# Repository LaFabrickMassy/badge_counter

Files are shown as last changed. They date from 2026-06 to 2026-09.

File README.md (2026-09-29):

# Compteur de fréquentation

## Objectif

Ce projet décrit un appareil qui permet de mesurer la fréquentation d'un lieu.  
Il a pour prérequis que tous les visiteurs disposeraient d'un badge à technologie NFC (typiquement salariés d'une entreprise), et badgent volontairement (présence nécessaire d'un panneau d'invitation au badgeage).

## Principe
Les badgeages sont enregistrés, et les statistiques sont accessible sur un serveur web local (hotspot) sous forme de statistiques par période de temps (nombre de visites mensuelles, nombre de visiteurs uniques mensuels).  
L'appareil est complètement autonome et n'est relié a rien si ce n'est son alimentation électrique.  
L'appareil n'enregistre que des identifiants de badge (nécessaire pour déterminer les visiteurs uniques), et n'a pas accès aux données personnelles (nom du porteur du badge par exemple).  

## Fonctionnement 
Au badgeage, un musique aléatoire (parmi 4 pour l’instant) est jouée.  
Il y a un « anti-passback », qui inhibe le badgeage pendant 1h pour chaque badge.  
Discriminant de badge : identifiant à n chiffres sur un bloc de m octets (cas des badges des salariés du site du FabLab).  

## Restitution des données

Un hotspot wifi et un serveur web sont démarrés lorsqu’on appuie sur le bouton de coté (et s’arrêtent au bout de 10 minutes). Les credentials (SSID, pwd, ip) sont affichés sur l’écran lorsque le serveur est actif.
Le serveur web donne accès aux données de fréquentation mensuelles sous forme tabulaire et graphique.
Il y a une page d’administration qui permet de  
- regler l’heure et de
- télécharger un fichier de synthèse des statistiques,
- téléchargerle fichier de log (timestamp, id badge)
- mais aussi d’écraser le fichier de log (attention, remise à zero des stats). Par sécurité, un backup est fait sur la carte, accessible uniquement physiquement (par lecture de la carte sd sur un pc).

# Ajout d'une nouvelle musique
1. décrire la partition sous forme d'une succession de notes. Chaque note est un couple (hauteur, durée). La hauteur de la note s'écrit suivant la notation anglo-saxone (voir documentation dans le fichier `songs.py` )
2. Rajouter cette liste de couples sous forme d'une variable liste python dans le fichier `songs.py` (voir exemples existants)
3. Rajouter cette variable à la liste des musiques `songs`, en précisant un tempo
4. En utilisant vscode, uploader le fichier songs.py sur le pico, à l'aide d'un cordon USB-microUSB

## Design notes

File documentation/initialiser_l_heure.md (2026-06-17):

# Initialiser l'heure du compteur de badge

Le compteur de badge dispose d'une horloge sauvegardée par pile. Il n'est donc pas nécessaire de réinitaliser l'heure à chaque fois qu'on le branche.  
Toutefois lorsque l'on doit changer la pile, l'heure n'est pas maintenue et il faut la réinitialiser à l'heure courante.  
L'appareil n'étant pas branché à internet, il ne peut pas déteminer l'heure sur le réseau. Une procédure manuelle est nécessaire.  

Cette procédure implique de modifier un script python pour saisir l'heure à laquelle on veut initialiser l'appareil, puis d'executer ce script.

## Procédure vscode

1. Condition initiale : l'outil VSCode est installé sur un ordinateur, ainsi que le plugin Micropico
2. Branchez le lecteur de badge en USB
3. Ouvrir VSCode
4. Créer ou ouvrir un répertoire micropico: ceci est nécessaire pour avoir accès au filesystème du Pico
    1. Dans vscode menu File / Open folder...
    2. Creez un nouveau répertoire quelconque et sélectionnez le pour ouverture
    3. Initialisez le en tant que répertoire micopico : 
        1. Ouvrez la palette des commandes (Ctrl + shift + p)
        2. Micropico: initialize micropico project
5. Accédez au file systeme du pico : dans la barre d'état en bas de vscode, cliquez sur "Toggle Mpy FS"
6. Un répertoire supplémentaire apparait dans le workspace : Mpy Remote Workspace
7. Cliquez sur le fichier "initialize_time.py" pour l'ouvrir
8. Modifiez la variable `initial_time_tuple` pour mettre l'heure cible
9. Enregistrez le fichier
10. Executez-le : le fichier sélectionné, cliquez sur "Run" dans la barre d'état
11. Le pico est maintenant à l'heure de la variable. Si la pile est chargé, cette heure est maintenue à jour avec le temps qui passe, sinon ce sera l'heure utilisée à chaque redémarrage.

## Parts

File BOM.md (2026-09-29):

# Bill Of Materials

## Composants

| Intitulé | Modèle | Prix indicatif |Lien |
| - | - | - |- |
| Microcontroleur | Rpi Pi Pico 2 W | 7,80 € | https://www.kubii.com/fr/cartes-micro-controleurs/4377-2357-raspberry-pi-pico-2-3272496319394.html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 |
| Carte de prototypage à souder | Upesy Medium | 2 € (x2) | https://www.upesy.fr/products/upesy-protoboard-breadboard-medium |
| Module NFC |  NFC RFID V3 PN532 | 4 €  | AliExpress |
| Module Real Time clock |  DS3231 AT24C32 IIC | 3,50 €  | AliExpress |
| Module SD Card |  SD CARD module | 1 €  | AliExpress |
| Ecran OLED |SSD1306 | 2 € | AliExpress |
| Buzzer Passif | Passive buzzer | 1,50 € | AliExpress |
| Bouton poussoir SPST | Bouton poussoir SPST (single pole, single throw)| Broutilles | AliExpress |
| Convertisseur DC / DC| LM2596 SMD | 1,10 € | AliExpress |
| Adaptateur secteur | Adaptateur secteur universel | 10,90 € | https://www.gotronic.fr/art-adaptateur-pce600.htm|
| Embase alimentation | Embase 5.5 x 2.1 | 0,40 € | https://www.gotronic.fr/art-embase-alim-sa215-14966.htm |
| Connecteurs JST-XH | Kit de connecteurs JST-XH (pas de 2.54mm) 2, 3, 4, 6 et 8 pins | 5 € |  AliExpress |
| Cables présertis JST XH | jst cables 10 cm | | AliExpress | 
| Connecteur Dupond | 2, 3, 4, 6 et 8 pins | Clopinettes | AliExpress |

## Consommables
- Fil d'étain à souder sans plomb
- Fil électrique 0,14mm²
- filament PLA pour imprimante 3D (~100g)
- chute de plexiglas 2,5mm
- quincaillerie :
  - vis M2.5 x 12
  - vis M2.5 x 40
  - vis M2 x 12
  - inserts laiton pour PLA M2.5
  - inserts laiton pour PLA M2

## Outils
- Fer à souder
- Pince coupante
- Pince à sertir
- tournevis multi tool
- scie (pour le plexiglas)
- perceuse (pour le plexiglas)
- PC (dev Python, modelisation du boitier)
- Cable USB-B - micro-USB
- Plaque d'essais sans soudure + fils de connexion

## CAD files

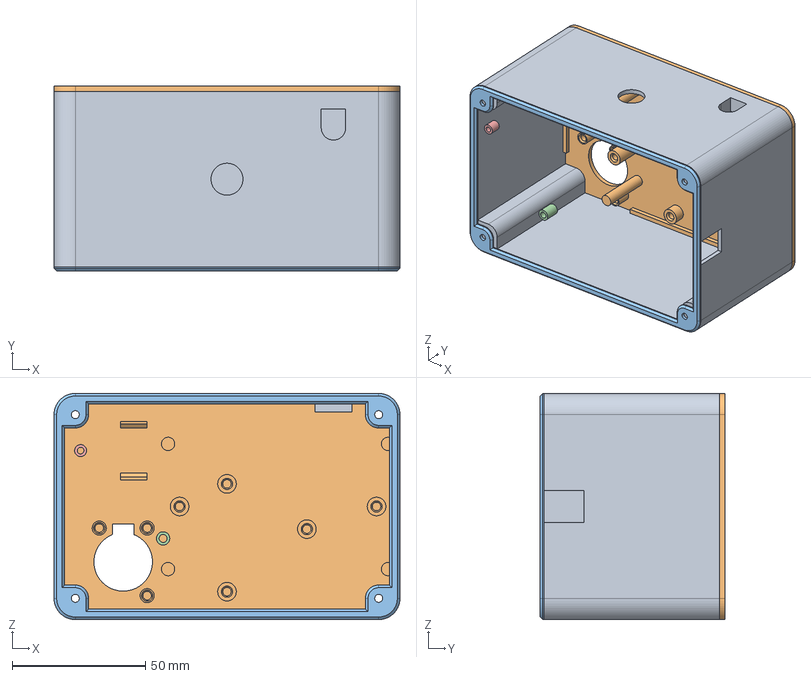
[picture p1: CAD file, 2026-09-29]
casing/casing_lecteur_badge.FCStd
130.0 x 69.5 x 85.0 mm
Walls
Back
Couvercle
EntretoiseM2.5
EntretroisM2

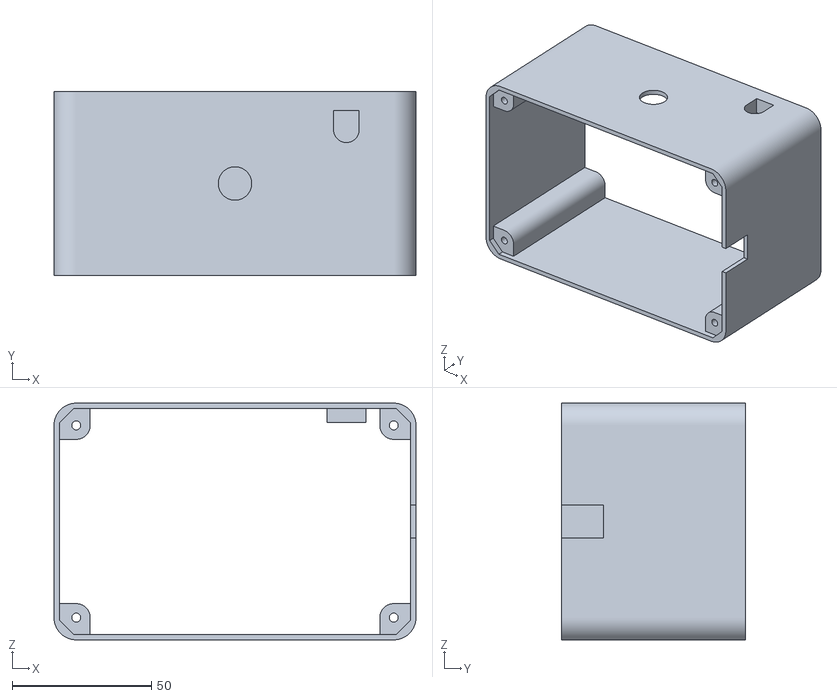
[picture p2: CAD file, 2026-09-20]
casing/stl/casing_lecteur_badge-Walls.stl
130.0 x 66.0 x 85.0

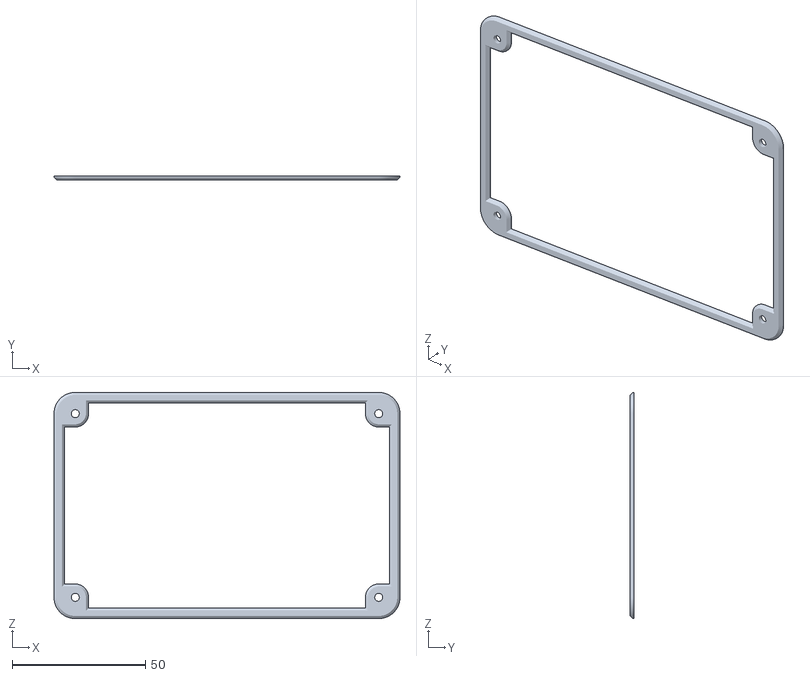
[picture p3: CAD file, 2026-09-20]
casing/stl/casing_lecteur_badge-Couvercle.stl
130.0 x 1.50 x 85.0

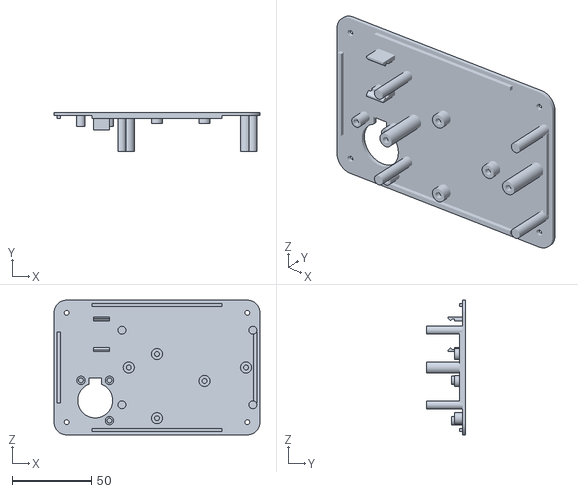
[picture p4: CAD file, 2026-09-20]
casing/stl/casing_lecteur_badge-Back.stl
130.0 x 24.8 x 85.0

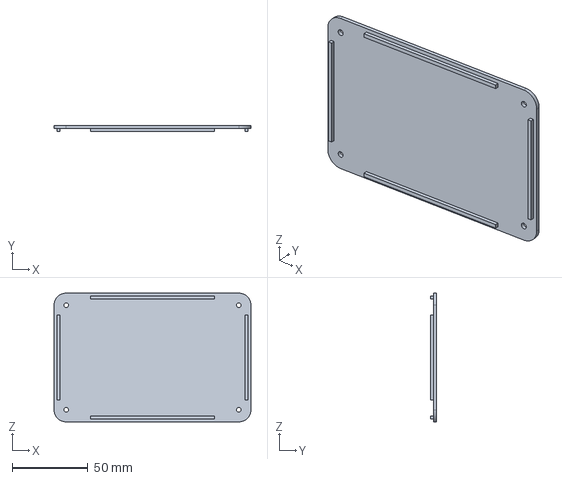
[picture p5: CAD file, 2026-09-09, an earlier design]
casing/casing_lecteur_badge_old.FCStd
130.0 x 4.00 x 85.0 mm

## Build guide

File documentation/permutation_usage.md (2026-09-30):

# Permutation de l'usage du lecteur de badge

Bien que le lecteur de badge ait été conçu pour mesurer la fréquentation d'un lieu unique, il est possible de permuter ponctuellement son utilisation pour des evenements spécifiques.

## Principe de fonctionnement

Le lecteur de badge met à jour à chaque évènement les informations de fréquentation dans deux fichiers internes :
- Fichier `data.txt` : Le lecteur de badge enregistre dans un fichier, à chaque badgeage, le numéro de badge et la date/heure de l'évènement.
- Fichier `stats.csv` : les données d'évènement sont exploitées pour en déduire le nombre de visites et de visiteurs uniques par période mensuelle

Il est possible de télécharger ces deux fichiers depuis l'interface web de l'appareil.  
L'interface web permet également d'uploader un fichier `data.txt` sur l'appareil, et d'écraser le fichier interne existant.

## Accès à l'interface web

1. Appuyer sur le bouton situé sur le coté de l'appareil.
2. Cela active un "hotspot" wifi ainsi qu'un serveur web.
3. Pour y accéder : 
    - noter les informations (nom du réseau wifi, password, adresse ip du serveur) qui s'affichent sur l'écran du lecteur de badge
    - sur un téléphone, ou un PC sans VPN tel que ceux du fablab, connectez-vous au réseau wifi du lecteur
    - ouvrez un navigateur web et saisissez l'adresse ip précisée en tant qu'adresse web (par exemple `192.168.4.1`)
    - le navigateur affiche les statistiques de fréquentation 
    - un lien vous permet d'accéder aux fonctions d'administration, y compris les fonctions de download et d'upload
4. Le service web se désactive après un nouvel appui sur le bouton, ou au bout de 10 minutes

## Procédure de permutation

1. Sauvergarde des données du Fablab : télécharger le fichier `data.txt` et le sauvegarder dans un répertoire dédié au Fablab
2. Mise à zéro des statistiques : créer un fichier `data.txt` vide et l'uploader sur le serveur web
3. Exploitation du lecteur pour le nouvel usage...
4. Exploitation des données : depuis le serveur web, downloader les fichiers `data.txt` et `stats.csv` dans un répertoire dédié à l'évenement
5. Restauration des données Fablab : sur le serveur web, uploader le fichier `data.txt` sauvergardé depuis l'étape 1.

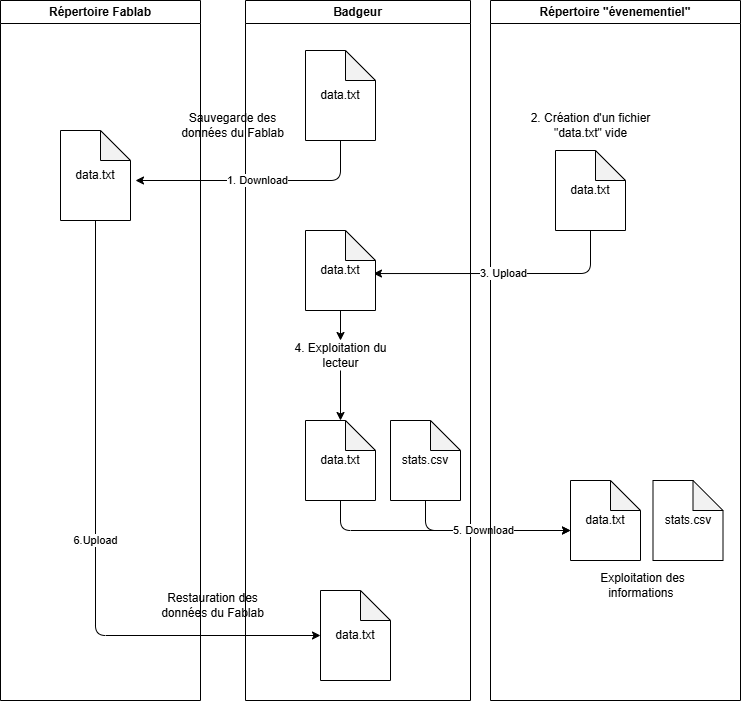
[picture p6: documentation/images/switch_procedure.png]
figure permutation


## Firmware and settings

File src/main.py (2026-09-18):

from machine import Pin, I2C, SPI
import machine
import network
import socket
import SSD1306
import urtc
import time
import sdcard
import uos
import NFC_PN532 as nfc
from buzzer import Buzzer, hello_world, game_over, bipbip
from attendancemodel import AttendanceModel, BadgingStatus
from webserver import WebService

class DisplayState:
    Counts = 0
    Params = 1

class BadgeCounter:
    
    def __init__(self, 
                 display_i2c=0, display_sda=20, display_scl=21,
                 rtc_i2c=1, rtc_sda=6, rtc_scl=7,
                 sd_spi=0, sd_mosi=3, sd_miso=4, sd_sck=2, sd_cs=1,
                 nfc_spi=1, nfc_mosi=11, nfc_miso=12, nfc_sck=10, nfc_rst=16, nfc_cs=13, nfc_irq=17,
                 buzzer_pin=15, button_pin=14, wifi_ssid="BadgeCounter", wifi_password="fablab2026"):
        
        # display communication
        self.display_i2c = I2C(id=display_i2c, sda=Pin(display_sda), scl=Pin(display_scl), freq=400000)
        
        # rtc communication
        self.rtc_i2c = I2C(id=rtc_i2c, scl=Pin(rtc_scl), sda=Pin(rtc_sda))
        
        # sd card communication
        self.sd_spi = machine.SPI(sd_spi,
                  baudrate=1000000,
                  polarity=0,
                  phase=0,
                  bits=8,
                  firstbit=machine.SPI.MSB,
                  sck=machine.Pin(sd_sck),
                  mosi=machine.Pin(sd_mosi),
                  miso=machine.Pin(sd_miso))
        self.sd_cs = sd_cs
        
        # nfc communication
        self.nfc_rst = nfc_rst
        self.nfc_cs = nfc_cs
        self.nfc_irq = nfc_irq
        self.nfc_spi = SPI(nfc_spi, baudrate=400000, sck=Pin(nfc_sck), mosi=Pin(nfc_mosi), miso=Pin(nfc_miso))
        
        # buzzer
        self.buzzer = Buzzer(buzzer_pin)
        self.button = Pin(button_pin, Pin.IN, Pin.PULL_UP)
        self.button_value = self.button.value()
        self.display_state = DisplayState.Counts
        self.webservice = None
        self.socket_server = None
        self.params_mode_started_at = None

        self.wifi_ssid = wifi_ssid
        self.wifi_password = wifi_password

        
    def init_display(self):
        self.display = SSD1306.SSD1306_I2C(128, 64, self.display_i2c)
        
    def init_rtc(self):
        self.rtc = urtc.DS3231(self.rtc_i2c)
        
    def init_sd(self):
        # Configure the Chip Select pin
        CS_SD = machine.Pin(self.sd_cs, machine.Pin.OUT)

        # Initialize the SD card object
        sd = sdcard.SDCard(self.sd_spi, CS_SD)

        # Mount the FAT filesystem
        vfs = uos.VfsFat(sd)
        uos.mount(vfs, "/sd")
        
    def init_nfc(self):
        rst = Pin(self.nfc_rst, Pin.OUT)
        rst.value(0)
        cs = Pin(self.nfc_cs, Pin.OUT)
        cs.on()
        ir = Pin(self.nfc_irq, Pin.IN)

        time.sleep(0.1)
        rst.value(1)
        time.sleep(0.5)  # Wait for PN532 to boot into SPI mode

        # SENSOR INIT
        self.pn532 = nfc.PN532(self.nfc_spi, cs, irq=ir, debug=False)
        ic, ver, rev, support = self.pn532.get_firmware_version()
        print('Found PN532 with firmware version: {0}.{1}'.format(ver, rev))

        # Configure PN532 to communicate with MiFare cards
        self.pn532.SAM_configuration()
        
    def init_buzzer(self):
        # there is nothing to init, just play song
        self.buzzer.play(hello_world)
        
    def init_data(self):
        # initialiser les données
        # le modele doit etre initialisé après rtc
        self.model = AttendanceModel(rtc=self.rtc, datafilename='/sd/data.txt')
        self.model.read_data()
        self.model.export_stats_to_csv()
        try:
            filesystem_stats = uos.statvfs('/sd')
            free_space = filesystem_stats[0] * filesystem_stats[4]
            free_space_percent = (filesystem_stats[4] * 100) / filesystem_stats[2]
            data_size = uos.stat(self.model.datafilename)[6]
            print("\nSD card free space: {} Mbytes ({:.2f}%)".format(
                free_space / (1024 * 1024), free_space_percent))
            print("data.txt size: {} bytes\n".format(data_size))
        except OSError as error:
            print("Unable to read SD card usage: {}".format(error))
        return

    def init_wifi_ap(self):
        self.wlan = network.WLAN(network.AP_IF)
        self.wlan.active(True)
        self.wlan.config(
            essid=self.wifi_ssid,
            password=self.wifi_password,
        )

        while not self.wlan.active():
            time.sleep_ms(100)

        print("Wi-Fi access point started")
        print("SSID:", self.wifi_ssid)
        print("Address: http://{}/".format(self.wlan.ifconfig()[0]))
    
    def init_webservice(self):
        self.socket_server = socket.socket()
        self.socket_server.setsockopt(socket.SOL_SOCKET, socket.SO_REUSEADDR, 1)
        self.socket_server.bind(("0.0.0.0", 80))
        self.socket_server.listen(1)
        self.socket_server.setblocking(False)
        
        self.webservice = WebService(self.model, self.socket_server)

    def start_params_mode(self):
        self.init_wifi_ap()
        self.init_webservice()
        self.params_mode_started_at = time.ticks_ms()

    def stop_params_mode(self):
        if self.socket_server is not None:
            self.socket_server.close()
            self.socket_server = None
        self.webservice = None
        self.params_mode_started_at = None
        self.wlan.active(False)

    def check_params_timeout(self):
        if (self.display_state == DisplayState.Params and
                self.params_mode_started_at is not None and
                time.ticks_diff(time.ticks_ms(), self.params_mode_started_at) >= 10 * 60 * 1000):
            self.display_state = DisplayState.Counts
            self.stop_params_mode()
        
    def refresh_display(self):

        if self.display_state == DisplayState.Counts :   
            current_datetime = self.rtc.datetime()
            sdate = f"{current_datetime.year:04d}-{current_datetime.month:02d}-{current_datetime.day:02d}"
            stime = f"{current_datetime.hour:02d}:{current_datetime.minute:02d}:{current_datetime.second:02d}"
            nvisits = f"Visites: {self.model.visits()}"

            self.display.fill(0) 
            self.display.text(sdate, 0,0, 1)
            self.display.text(stime, 0,10, 1)
            self.display.text(nvisits, 0, 24, 1)
            self.display.show()  
        else :
            self.display.fill(0) 
            self.display.text("SSID :", 0,0, 1)
            self.display.text(f"{self.wifi_ssid}", 0, 10, 1)
            self.display.text("Pwd :", 0, 22, 1)
            self.display.text(f"{self.wifi_password}", 0, 32, 1)
            self.display.text("ip :", 0, 44, 1)
            self.display.text(f"{self.wlan.ifconfig()[0]}", 0, 54, 1)
            self.display.show()  


        
    def read_badge(self):
        uid, length = self.pn532.read_passive_target_fablab(timeout=1000) 
        if uid is not None:
            numbers = [i for i in uid]
            print(f"UID: {numbers}, frame_length: {length}")
            # play(imperial_march)
            result = self.model.handle_event(uid, length)
            print(f"Result : {result}")
            if result == BadgingStatus.PASSBACK:
                self.buzzer.play(game_over)
                self.refresh_display()
            elif result == BadgingStatus.NOT_THALES:
                self.buzzer.play(bipbip)
                self.refresh_display()
            elif result == BadgingStatus.OK:
                self.buzzer.play_random_song()
                self.refresh_display()
                self.model.export_stats_to_csv()

    def check_button(self):
        button_value = self.button.value()
        if button_value != self.button_value: # button changed
            self.button_value = button_value
            if button_value == False: # button pressed
                # switch diplay state
                self.display_state = DisplayState.Counts if (self.display_state == DisplayState.Params) else DisplayState.Params
                if self.display_state == DisplayState.Params:
                    self.start_params_mode()
                else:
                    self.stop_params_mode()
        
    def start(self):
        try:
            self.init_display()
        except:
            self.buzzer.play(game_over)
            return

        try:
            self.init_nfc()
        except:
            # Common initialisation error
            self.display.fill(0)
            self.display.text("NFC error", 0, 0, 1)
            self.display.show()
            self.buzzer.play(game_over)
            return

        try:
            self.init_rtc()
            self.init_sd()          
            self.init_data()
            self.refresh_display()
            self.init_buzzer()
        except:
            self.display.fill(0)
            self.display.text("Init error", 0, 0, 1)
            self.display.show()
            self.buzzer.play(game_over)
            return
        
        while(True):
            if self.webservice is not None:
                self.webservice.poll()
            self.read_badge()
            self.check_button()
            self.check_params_timeout()
            self.refresh_display()
        
if __name__ == "__main__":
    counter = BadgeCounter()
    counter.start()
        

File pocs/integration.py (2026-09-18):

# Objectif : intégrer l'ensemble des périphs : rtc, écran, buzzer, lecteur de badge, lecteur de carte sd

from machine import Pin, I2C, SPI
import SSD1306
import time
#import datetime
import urtc
import NFC_PN532 as nfc
from buzzer import play, imperial_march
import sdcard
import uos

# Configure the Chip Select pin
CS_SD = machine.Pin(1, machine.Pin.OUT)

# Initialize SPI1 with the specified pins and baud rate
spi_SD = machine.SPI(0,
                  baudrate=1000000,
                  polarity=0,
                  phase=0,
                  bits=8,
                  firstbit=machine.SPI.MSB,
                  sck=machine.Pin(2),
                  mosi=machine.Pin(3),
                  miso=machine.Pin(4))

# Initialize the SD card object
sd = sdcard.SDCard(spi_SD, CS_SD)
data_filename = "/sd/data.txt"

# Mount the FAT filesystem
vfs = uos.VfsFat(sd)
uos.mount(vfs, "/sd")

print("SD card mounted successfully!")
print("Files on SD card:", uos.listdir("/sd"))

# Create a file and write data to it
with open("/sd/test.txt", "w") as file:
    print("Writing to data.txt...")
    file.write("Welcome to microcontrollerslab!\r\n")
    file.write("This is a test\r\n")

print("Write complete.")

# Open the file and read the data back
with open("/sd/test.txt", "r") as file:
    print("Reading data.txt...")
    data = file.read()
    print(data)

# Initialise les derniers passages à partir du fichier de données
def initialize_passes():
    result = {}
    with open(data_filename, 'r') as data_file:
        for line in data_file:
            s_date, badge = line.split(',')
            # convert here s_date into time
            result[badge.strip()] = s_date
            print(f"date: {result[badge.strip()]}, id: {badge.strip()}")

    return result


days_of_week = ['Monday', 'Tuesday', 'Wednesday', 'Thursday', 'Friday', 'Saturday', 'Sunday']

# Initialize RTC (connected to I2C)
i2c1 = I2C(1, scl=Pin(7), sda=Pin(6))
rtc = urtc.DS3231(i2c1)

# display initialisation
i2c0 = I2C(sda=Pin(20), scl=Pin(21), freq=400000)
print('Scan i2c bus...')
devices = i2c0.scan()

print('Scan i2c bus...')
devices = i2c0.scan()

if len(devices) == 0:
  print("No i2c device !")
else:
  print('i2c devices found:',len(devices))

  for device in devices:  
    print("Decimal address: ",device," | Hexa address: ",hex(device))

display = SSD1306.SSD1306_I2C(128, 64, i2c0)

current_datetime = rtc.datetime()
sdate = f"{current_datetime.year:04d}-{current_datetime.month:02d}-{current_datetime.day:02d}"
stime = f"{current_datetime.hour:02d}:{current_datetime.minute:02d}:{current_datetime.second:02d}"

display.text('Hello, World!', 0, 0, 1)
display.text(sdate, 0,16, 1)
display.text(stime, 0,26, 1)
display.show()

last_passes = initialize_passes()


# nfc initialisation
rst = Pin(16, Pin.OUT)
rst.value(0)
time.sleep(0.1)
rst.value(1)
time.sleep(0.5)  # Wait for PN532 to boot into SPI mode

# SPI
spi_dev = SPI(1, baudrate=400000, sck=Pin(10), mosi=Pin(11), miso=Pin(12))
cs = Pin(13, Pin.OUT)
cs.on()
ir = Pin(17, Pin.IN)

# SENSOR INIT
pn532 = nfc.PN532(spi_dev,cs, irq=ir, debug=False)
ic, ver, rev, support = pn532.get_firmware_version()
print('Found PN532 with firmware version: {0}.{1}'.format(ver, rev))

# Configure PN532 to communicate with MiFare cards
pn532.SAM_configuration()


# FUNCTION TO READ 
def read_nfc(dev, tmot):
    """Accepts a device and a timeout in millisecs """
    # print('Reading...')
    uid = dev.read_passive_target(timeout=tmot)
    if uid is None:
        print('.', end='')
    else:
        numbers = [i for i in uid]
        badge_ID = '{}-{}-{}-{}'.format(*numbers)
        
        current_datetime = rtc.datetime()
        sdate = f"{current_datetime.year:04d}-{current_datetime.month:02d}-{current_datetime.day:02d}"
        stime = f"{current_datetime.hour:02d}:{current_datetime.minute:02d}:{current_datetime.second:02d}"
        ture = rtc.get_temperature()
        
        display.fill(0) 
        display.text(badge_ID, 0, 0, 1)
        display.text(sdate, 0, 16, 1)
        display.text(stime, 0, 32, 1)
        display.text(f"{ture} deg C", 0, 48, 1)
        display.show()
        
        with open(data_filename, "a") as file:
            file.write(f"{sdate} {stime}, {badge_ID}\r\n")
        
        print('Found card with UID:', [hex(i) for i in uid])
        print('Number_id: {}'.format(badge_ID))
        play(imperial_march)
        time.sleep(1)
        
while True:
    read_nfc(pn532, 2000)
    time.sleep(0.1)

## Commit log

2026-09-14 modifs on casing
    [casing_lecteur_badge.FCStd]
2026-09-14 work on casing
    [casing_lecteur_badge.FCStd]
2026-09-16 add enjoliveur
    [casing_lecteur_badge.FCStd]
2026-09-18 improve buzzer mgt and initialisation sequence
    [buzzer.py, main.py, songs.py]
2026-09-20 Add chart
    [casing_lecteur_badge-Back.stl, casing_lecteur_badge-Couvercle.stl, casing_lecteur_badge-Walls.stl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]
2026-09-23 Revise SPST button description and section title
    Updated the description of the SPST push button and corrected the section title from 'Matériels' to 'Outils'.
2026-09-23 add spacers
    [casing_lecteur_badge.FCStd]
2026-09-30 switch procedure
